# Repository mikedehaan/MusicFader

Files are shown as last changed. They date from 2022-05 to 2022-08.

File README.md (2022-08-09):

# MusicFader

## Materials Used

16CH Analog Digital Multiplexer
https://www.amazon.com/gp/product/B07K7JF3HX/

NodeMCUv1.0 Arduino Board
https://www.amazon.com/gp/product/B081CSJV2V

Fielect 10k Fader 
https://www.amazon.com/gp/product/B08CD8QHR6

Updated to no longer use a switch.  Just plug in with the first fader fully up to enter setup mode.

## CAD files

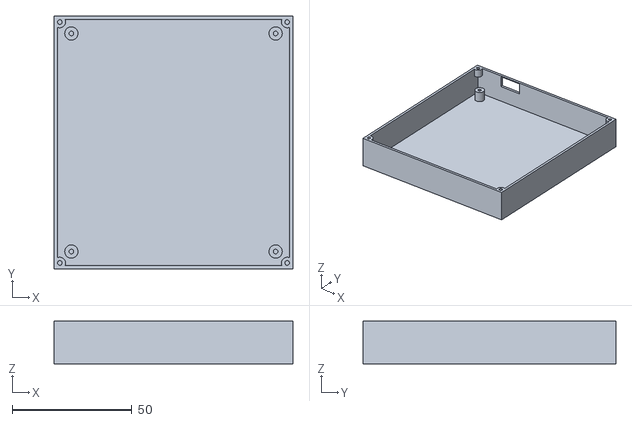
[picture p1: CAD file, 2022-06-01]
src/main/3dprint/TwoFaderBottom.stl
99.7 x 105.4 x 17.9

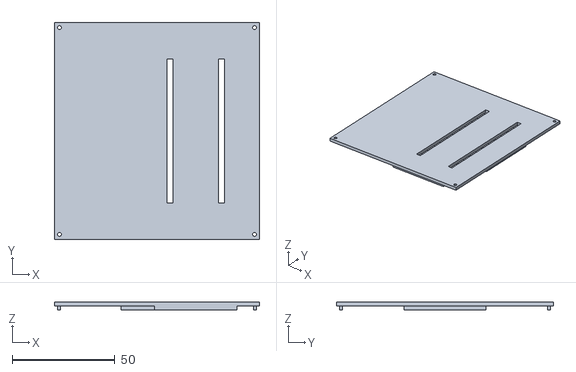
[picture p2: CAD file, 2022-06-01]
src/main/3dprint/TwoFaderTop.stl
99.7 x 105.4 x 4.00

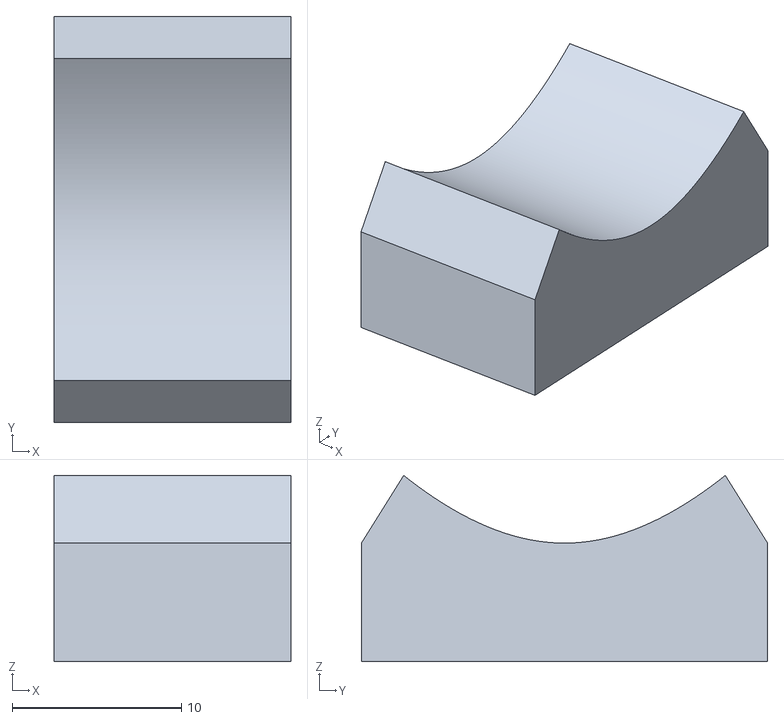
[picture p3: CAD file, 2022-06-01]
src/main/3dprint/FaderKnob.stl
14.0 x 24.0 x 11.0

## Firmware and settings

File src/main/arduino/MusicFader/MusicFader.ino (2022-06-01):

#include <ESP8266WiFi.h>
#include <WiFiUdp.h>
#include <OSCMessage.h>
#include <OSCBundle.h>
#include "Mixer.h"
#include "Fader.h"
#include "Global.h"

struct EepromSavedData {
    char ssid[33];
    char password[65];
    int fader1Bus;
    int fader1Channel;
    int fader2Bus;
    int fader2Channel;
};

EepromSavedData eepromSavedData;

#define UDP_PORT 10024

#define MUX_S0  D0
#define MUX_S1  D1
#define MUX_S2  D2
#define MUX_S3  D3
#define MUX_SIG A0

#define STATE_SETUP   0
#define STATE_RUNTIME 1

const unsigned int inPort = 8888;

int systemState = 0;
unsigned int wifiStatus = 0;

Fader *fader1;
Fader *fader2;

void muxSetup();

void oscSetup() {
    pinMode(LED_BUILTIN, OUTPUT);
    WiFi.mode(WIFI_STA);
    WiFi.setSleepMode(WIFI_NONE_SLEEP);
    delay(1000);

    loadCredentials();

    Serial.println();
    Serial.print("Configuring access point...");

    String ssidString = "";
    String passwordString = "";
    ssidString += eepromSavedData.ssid;
    passwordString += eepromSavedData.password;
    
    WiFi.begin(ssidString, passwordString);

    while (WiFi.status() != WL_CONNECTED) {
        delay(500);
        Serial.print(".");
    }

    Serial.println("");
    Serial.println("WiFi connected");
    Serial.print("IP address: ");
    Serial.println(WiFi.localIP());

    WiFi.setAutoReconnect(true);
    WiFi.persistent(true);

    // Parse the localIP and change to the broadcast IP
    String ipAddressString;
    ipAddressString += WiFi.localIP().toString();

    Serial.print("NETMASK: ");
    Serial.println(WiFi.subnetMask());

    uint8_t  netAddress1 = WiFi.localIP()[0] & WiFi.subnetMask()[0];
    uint8_t  netAddress2 = WiFi.localIP()[1] & WiFi.subnetMask()[1];
    uint8_t  netAddress3 = WiFi.localIP()[2] & WiFi.subnetMask()[2];
    uint8_t  netAddress4 = WiFi.localIP()[3] & WiFi.subnetMask()[3];

    uint8_t  broadcast1 = netAddress1 | ~WiFi.subnetMask()[0];
    uint8_t  broadcast2 = netAddress2 | ~WiFi.subnetMask()[1];
    uint8_t  broadcast3 = netAddress3 | ~WiFi.subnetMask()[2];
    uint8_t  broadcast4 = netAddress4 | ~WiFi.subnetMask()[3];

    String broadcastString;
    broadcastString += broadcast1;
    broadcastString += ".";
    broadcastString += broadcast2;
    broadcastString += ".";
    broadcastString += broadcast3;
    broadcastString += ".";
    broadcastString += broadcast4;

    IPAddress broadcastIp;
    broadcastIp.fromString(broadcastString);
    Serial.print("Broadcast IP: ");
    Serial.println(broadcastIp);

    // At this point, we're on the network.
    // Now, how do we send data.....
    WiFiUDP UDP;
    UDP.begin(inPort);

    mixer = new Mixer(UDP, broadcastIp);

    // When bus is set to 0, this refers to the MainLR (FOH)
    // Otherwise, bus 1-6 refers to the 6 buses
    int bus = eepromSavedData.fader1Bus;

    // Then channel is set to 0, this refers to the master fader
    // So, bus 0 channel 0 is the MainLR master fader
    // bus 1 channel 0 will be the bus 1 master fader
    // Otherwise, channel can be from 1-16 referring to the 16 channels
    int channel = eepromSavedData.fader1Channel;

    // Still need to determine a pattern for aux
    // /rtn/aux/mix/fader
    // /rtn/aux/mix/on

    fader1 = new Fader(0, MUX_S0, MUX_S1, MUX_S2, MUX_S3, MUX_SIG, mixer, bus, channel);

    #ifdef USE_MUX
    fader2 = new Fader(1, MUX_S0, MUX_S1, MUX_S2, MUX_S3, MUX_SIG, mixer, eepromSavedData.fader2Bus, eepromSavedData.fader2Channel);
    #endif
}

void setup() {
    delay(1000);  
    Serial.begin(115200);

    muxSetup();

    // We're only using this fader to check if we should enter setup mode.
    Fader setupFader(0, MUX_S0, MUX_S1, MUX_S2, MUX_S3, MUX_SIG, mixer, 1, 1);

    if (setupFader.convertToMixerValue(setupFader.getRawValue()) > 0.9) {
        Serial.println("Setup switch is on.");
        systemState = STATE_SETUP;
        captivePortalSetup();
    } else {
        Serial.println("Setup switch is off.");
        systemState = STATE_RUNTIME;
        oscSetup();
    }
}

void loop() {
    if (systemState == STATE_RUNTIME) {
        if (!mixer->connected) {
            // Broadcast a request for all mixers to respond
            // Only send this once
            if (!mixer->wasFindRequestSent()) {
                mixer->findMixers();
            }
    
            // Listen for a response from the mixer.
            mixer->receiveData();
        } else {
            fader1->run();
            #ifdef USE_MUX
            fader2->run();
            #endif
            mixer->run();

            //mixer->receiveData();
        }


        unsigned int s = WiFi.status();
        if (s != wifiStatus) {
            Serial.print("Wifi status changed from: ");
            Serial.print(wifiStatus);
            Serial.print(" to ");
            Serial.println(s);

            wifiStatus = s;
        }

    } else if (systemState == STATE_SETUP) {
        captivePortalLoop();
    }
}

void muxSetup() {

    //Mux control pins
    int s0 = MUX_S0;
    int s1 = MUX_S1;
    int s2 = MUX_S2;
    int s3 = MUX_S3;

    Serial.println("Mux configured to use:");
    Serial.print("S0: ");
    Serial.println(s0);
    Serial.print("S1: ");
    Serial.println(s1);
    Serial.print("S2: ");
    Serial.println(s2);
    Serial.print("S3: ");
    Serial.println(s3);

    pinMode(s0, OUTPUT);
    pinMode(s1, OUTPUT);
    pinMode(s2, OUTPUT);
    pinMode(s3, OUTPUT);

    digitalWrite(s0, LOW);
    digitalWrite(s1, LOW);
    digitalWrite(s2, LOW);
    digitalWrite(s3, LOW);

    Serial.println("Mux Intialized");    
}

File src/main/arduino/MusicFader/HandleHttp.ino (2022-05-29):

#include "Global.h"

String createDropDown(String title, String name, int min, int max, int selectedValue) {
    String result;

    result += title;
    result += F("<select name='");
    result += name + F("'>");
    for (int i = min; i <= max; i++) {
        if (selectedValue == i) {
            result += F("<option selected value='");
        } else {
            result += F("<option value='");
        }

        result += i;
        result += F("'>");
        result += i;
        result += F("</option>");
    }
    result += F("</select>");

    return result;
}

/** Redirect to captive portal if we got a request for another domain. Return true in that case so the page handler do not try to handle the request again. */
boolean captivePortal() {
    if (!isIp(server.hostHeader()) && server.hostHeader() != (String(myHostname) + ".local")) {
        Serial.println("Request redirected to captive portal");
        server.sendHeader("Location", String("http://") + toStringIp(server.client().localIP()), true);
        server.send(302, "text/plain", "");  // Empty content inhibits Content-length header so we have to close the socket ourselves.
        server.client().stop();              // Stop is needed because we sent no content length
        return true;
    }
    return false;
}

/** Wifi config page handler */
void handleWifi() {
    server.sendHeader("Cache-Control", "no-cache, no-store, must-revalidate");
    server.sendHeader("Pragma", "no-cache");
    server.sendHeader("Expires", "-1");

    String Page;
    Page += F("<!DOCTYPE html><html lang='en'><head>"
            "<meta name='viewport' content='width=device-width'>"
            "<title>CaptivePortal</title></head><body>"
            "<h3>Music Fader Setup</h1>");
    Page += F("<style>body { font-size: 2em; }select  { font-size: 1em; } .sf { font-size: 8px; } .btn { height: 75px; width: 200px;}</style>");

    Page += F("<table><tr><th align='left'>WLAN list</th></tr>");
    Serial.println("scan start");
    int n = WiFi.scanNetworks();
    Serial.println("scan done");
    if (n > 0) {
        for (int i = 0; i < n; i++) { Page += String(F("\r\n<tr><td class='sf'>SSID ")) + WiFi.SSID(i) + ((WiFi.encryptionType(i) == ENC_TYPE_NONE) ? F(" ") : F(" *")) + F(" (") + WiFi.RSSI(i) + F(")</td></tr>"); }
    } else {
        Page += F("<tr><td>No WLAN found</td></tr>");
    }
    Page += F("</table>\r\n<br />");

    String htmlSsid = "";
    htmlSsid += eepromSavedData.ssid;

    String htmlPassword = "";
    htmlPassword += eepromSavedData.password;

    Page += F("<form method='POST' action='wifisave'><b>Connect to network:</b><hr/>");
    Page += F("<input type='text' placeholder='network' name='n' value='");
    Page += htmlSsid;
    Page += F("'/>");

    Page += F("<br />");

    Page += F("<input type='password' placeholder='password' name='p' value='");
    Page += htmlPassword;
    Page += F("'/>");
    Page += F("<br /><br />");

    // Fader 1
    Page += F("<b>Fader1</b><hr />");
    Page += createDropDown("Bus:",     "b1", 0, 6,  eepromSavedData.fader1Bus);
    //Page += F("<br />");
    Page += createDropDown("Channel:", "c1", 0, 16, eepromSavedData.fader1Channel);
    Page += F("<br />");

    #ifdef USE_MUX
    Page += F("<b>Fader2</b><hr />");
    Page += createDropDown("Bus:",     "b2", 0, 6,  eepromSavedData.fader2Bus);
    //Page += F("<br />");
    Page += createDropDown("Channel:", "c2", 0, 16, eepromSavedData.fader2Channel);
    #endif

    Page += F("<br /><input type='submit' class='btn' value='Save'/>");
    Page += F("</form><br/><br/><br/><br/>");

    Page += String(F("<hr/><table><tr><th align='left'>Device Config</th></tr>"
                   "<tr><td class='sf'>SSID "))
          + String(softAP_ssid) + F("</td></tr>"
                                    "<tr><td class='sf'>IP ")
          + toStringIp(WiFi.softAPIP()) + F("</td></tr>"
                                            "</table>"
                                            "\r\n<br />");

    Page += F("</body></html>");

            
    server.send(200, "text/html", Page);
    server.client().stop();  // Stop is needed because we sent no content length
}

/** Handle the WLAN save form and redirect to WLAN config page again */
void handleWifiSave() {
    Serial.println("wifi save");
    server.arg("n").toCharArray(eepromSavedData.ssid, sizeof(eepromSavedData.ssid) - 1);
    server.arg("p").toCharArray(eepromSavedData.password, sizeof(eepromSavedData.password) - 1);

    eepromSavedData.fader1Bus = server.arg("b1").toInt();
    eepromSavedData.fader1Channel = server.arg("c1").toInt();
    eepromSavedData.fader2Bus = server.arg("b2").toInt();
    eepromSavedData.fader2Channel = server.arg("c2").toInt();

    server.sendHeader("Location", "wifi", true);
    server.sendHeader("Cache-Control", "no-cache, no-store, must-revalidate");
    server.sendHeader("Pragma", "no-cache");
    server.sendHeader("Expires", "-1");
    server.send(302, "text/plain", "");  // Empty content inhibits Content-length header so we have to close the socket ourselves.
    server.client().stop();              // Stop is needed because we sent no content length
    saveCredentials();
    connect = strlen(eepromSavedData.ssid) > 0;  // Request WLAN connect with new credentials if there is a SSID
}

void handleNotFound() {
    if (captivePortal()) {  // If captive portal redirect instead of displaying the error page.
        return;
    }
    String message = F("File Not Found\n\n");
    message += F("URI: ");
    message += server.uri();
    message += F("\nMethod: ");
    message += (server.method() == HTTP_GET) ? "GET" : "POST";
    message += F("\nArguments: ");
    message += server.args();
    message += F("\n");

    for (uint8_t i = 0; i < server.args(); i++) { message += String(F(" ")) + server.argName(i) + F(": ") + server.arg(i) + F("\n"); }
    server.sendHeader("Cache-Control", "no-cache, no-store, must-revalidate");
    server.sendHeader("Pragma", "no-cache");
    server.sendHeader("Expires", "-1");
    server.send(404, "text/plain", message);
}

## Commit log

2022-05-21 Initial Commit
    Project works when uploaded and SSID/PW is set.
    [CircuitBoard2.fzz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]
2022-05-22 Fixed broadcast IP calculation.
    [MusicFader.ino]
2022-05-25 Modified setup mode
    Instead of a separate switch, we now just raise the first fader to max value before booting.
2022-05-25 Removed switch from pcb design.
    [CircuitBoard2.fzz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]
2022-05-29 Updated circuit to remove false grounding from the fader.
    The fader chassis should NOT be grounded.
    [CircuitBoard2.fzz]
2022-05-29 Updated Gerber files with new design
    [CircuitBoard2.fzz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]
2022-05-29 Fixed bus aasignment
    Had channel and bus flipped.
    Also added logging for saved settings.
    [Credentials.ino, Fader.cpp, Mixer.cpp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]
2022-05-30 Attempting to fix Wifi disconnects.
    [Fader.cpp, Mixer.cpp, MusicFader.ino]
2022-06-01 Removed no-longer planned changes, and added 3d print files.
    [FaderKnob.stl, TwoFaderBottom.stl, TwoFaderTop.stl]
2022-08-09 Removed switch requirement
